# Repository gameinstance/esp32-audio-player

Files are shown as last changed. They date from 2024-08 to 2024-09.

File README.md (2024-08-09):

GameInstance.com esp32 audio player

# esp32-audio-player - GameInstance.com

A PCM56 stereo player powered by ESP32.

Follow the instructions on the [Firmware](./firmware) page to build the code, then flash it onto the
[Hardware](./hardware).

Further details on: https://gameinstance.com/post/106/ESP32-PCM56-player

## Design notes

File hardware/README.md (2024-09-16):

GameInstance.com esp32 audio player

# esp32-audio-player - GameInstance.com

An ESP32 audio player powered by PCM56 DAC chips.

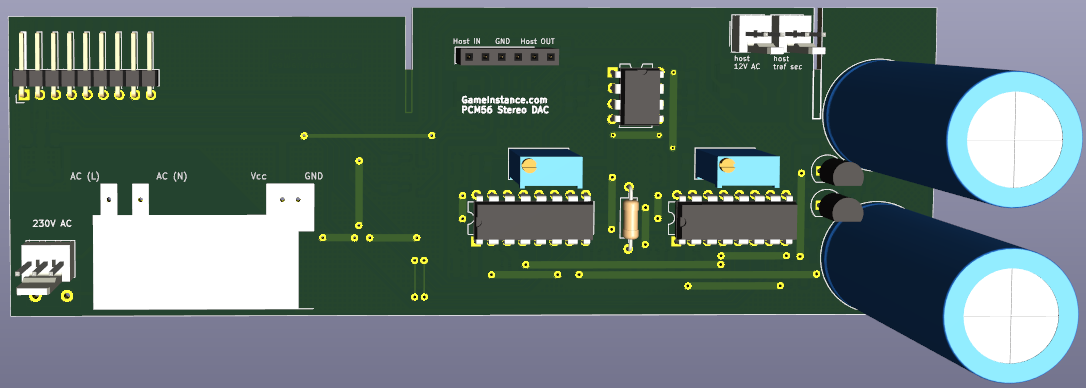
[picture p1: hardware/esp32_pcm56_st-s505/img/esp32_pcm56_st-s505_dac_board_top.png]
ESP32 DAC56 player implementation for Technics ST-S505


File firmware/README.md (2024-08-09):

GameInstance.com esp32 audio player

# esp32-audio-player - GameInstance.com

An ESP32 audio player powered by PCM56 DAC chips.

## Setup

Create the work directory in which you'll clone the **esp32-audio-player** repository and its
dependencies: **basics**, **stream**, **audio**, **esp-idf-cpp**.

```
mkdir ~/gameinstance
cd ~/gameinstance
git clone https://github.com/gameinstance/basics
git clone https://github.com/gameinstance/stream
git clone https://github.com/gameinstance/audio
git clone https://github.com/gameinstance/esp-idf-cpp
git clone https://github.com/gameinstance/esp32-audio-player
```

## Prerequisite

* [ESP-IDF](https://docs.espressif.com/projects/esp-idf/en/stable/esp32/get-started/index.html) environment,
* the [player hardware](../hardware) implementation or a breadboard prototype,
* a serial connection to the ESP32 controller with control over the flashing GPIO pins,
* WIFI_AP and WIFI_PASS configuration in **esp32-audio-player/firmware/main/esp32-audio-player.cc** .

## Build and flash

```
cd ~/gameinstance/esp32-audio-player/firmware
idf.py build flash monitor

```

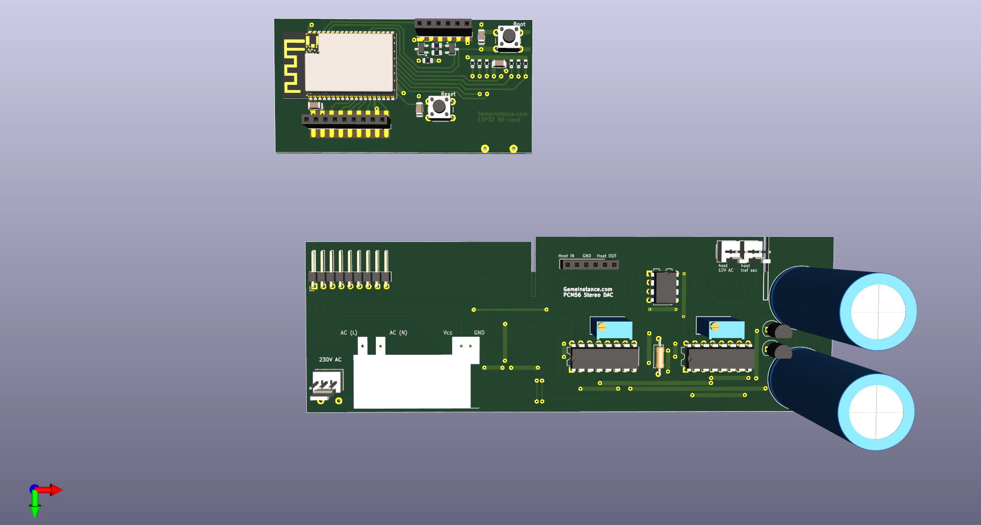
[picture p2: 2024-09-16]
hardware/esp32_pcm56_st-s505/img/esp32_pcm56_simple12.png

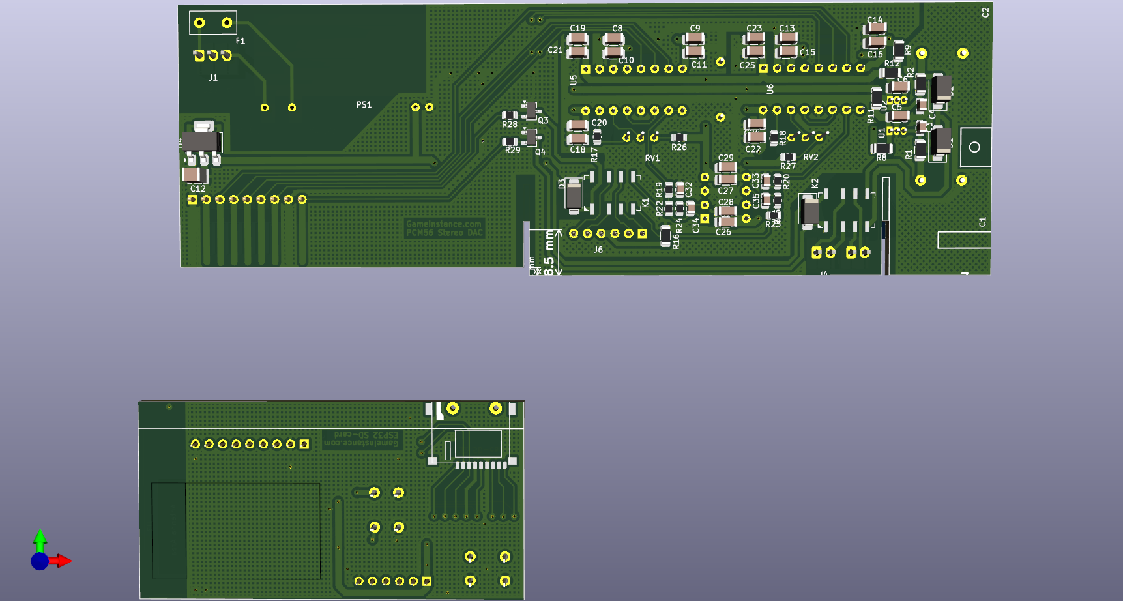
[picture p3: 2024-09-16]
hardware/esp32_pcm56_st-s505/img/esp32_pcm56_simple10.png

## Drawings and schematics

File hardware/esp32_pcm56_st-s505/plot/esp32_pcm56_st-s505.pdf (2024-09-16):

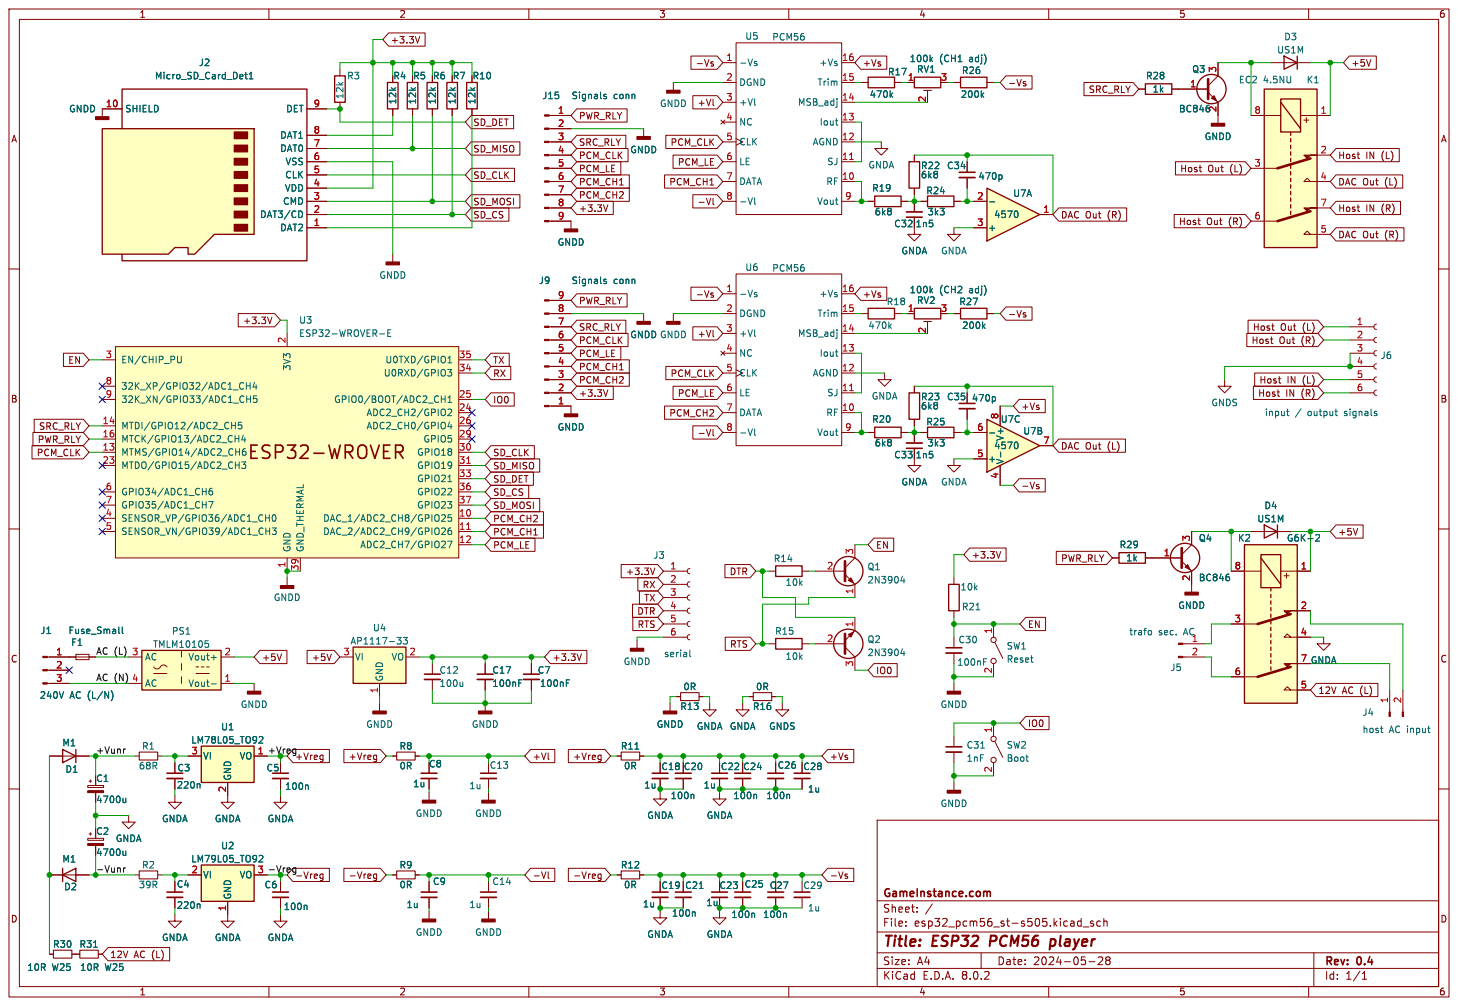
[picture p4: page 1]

Iout 13 MSB_adj 14 Trim 15 +Vs 16 DGND 2 +Vl 3 NC 4 CLK 5
3k3 GNDA R17

6k8 GNDA
input / output signals GND
2N3904 GNDD þÿESP32--WROVER GND

1 VI 2 VO 3 GNDA GNDA GNDA GNDA C6

Id: 1/1 Title: ESP32 PCM56 player File: esp32_pcm56_st-s505.kicad_sch Sheet: / GameInstance.com

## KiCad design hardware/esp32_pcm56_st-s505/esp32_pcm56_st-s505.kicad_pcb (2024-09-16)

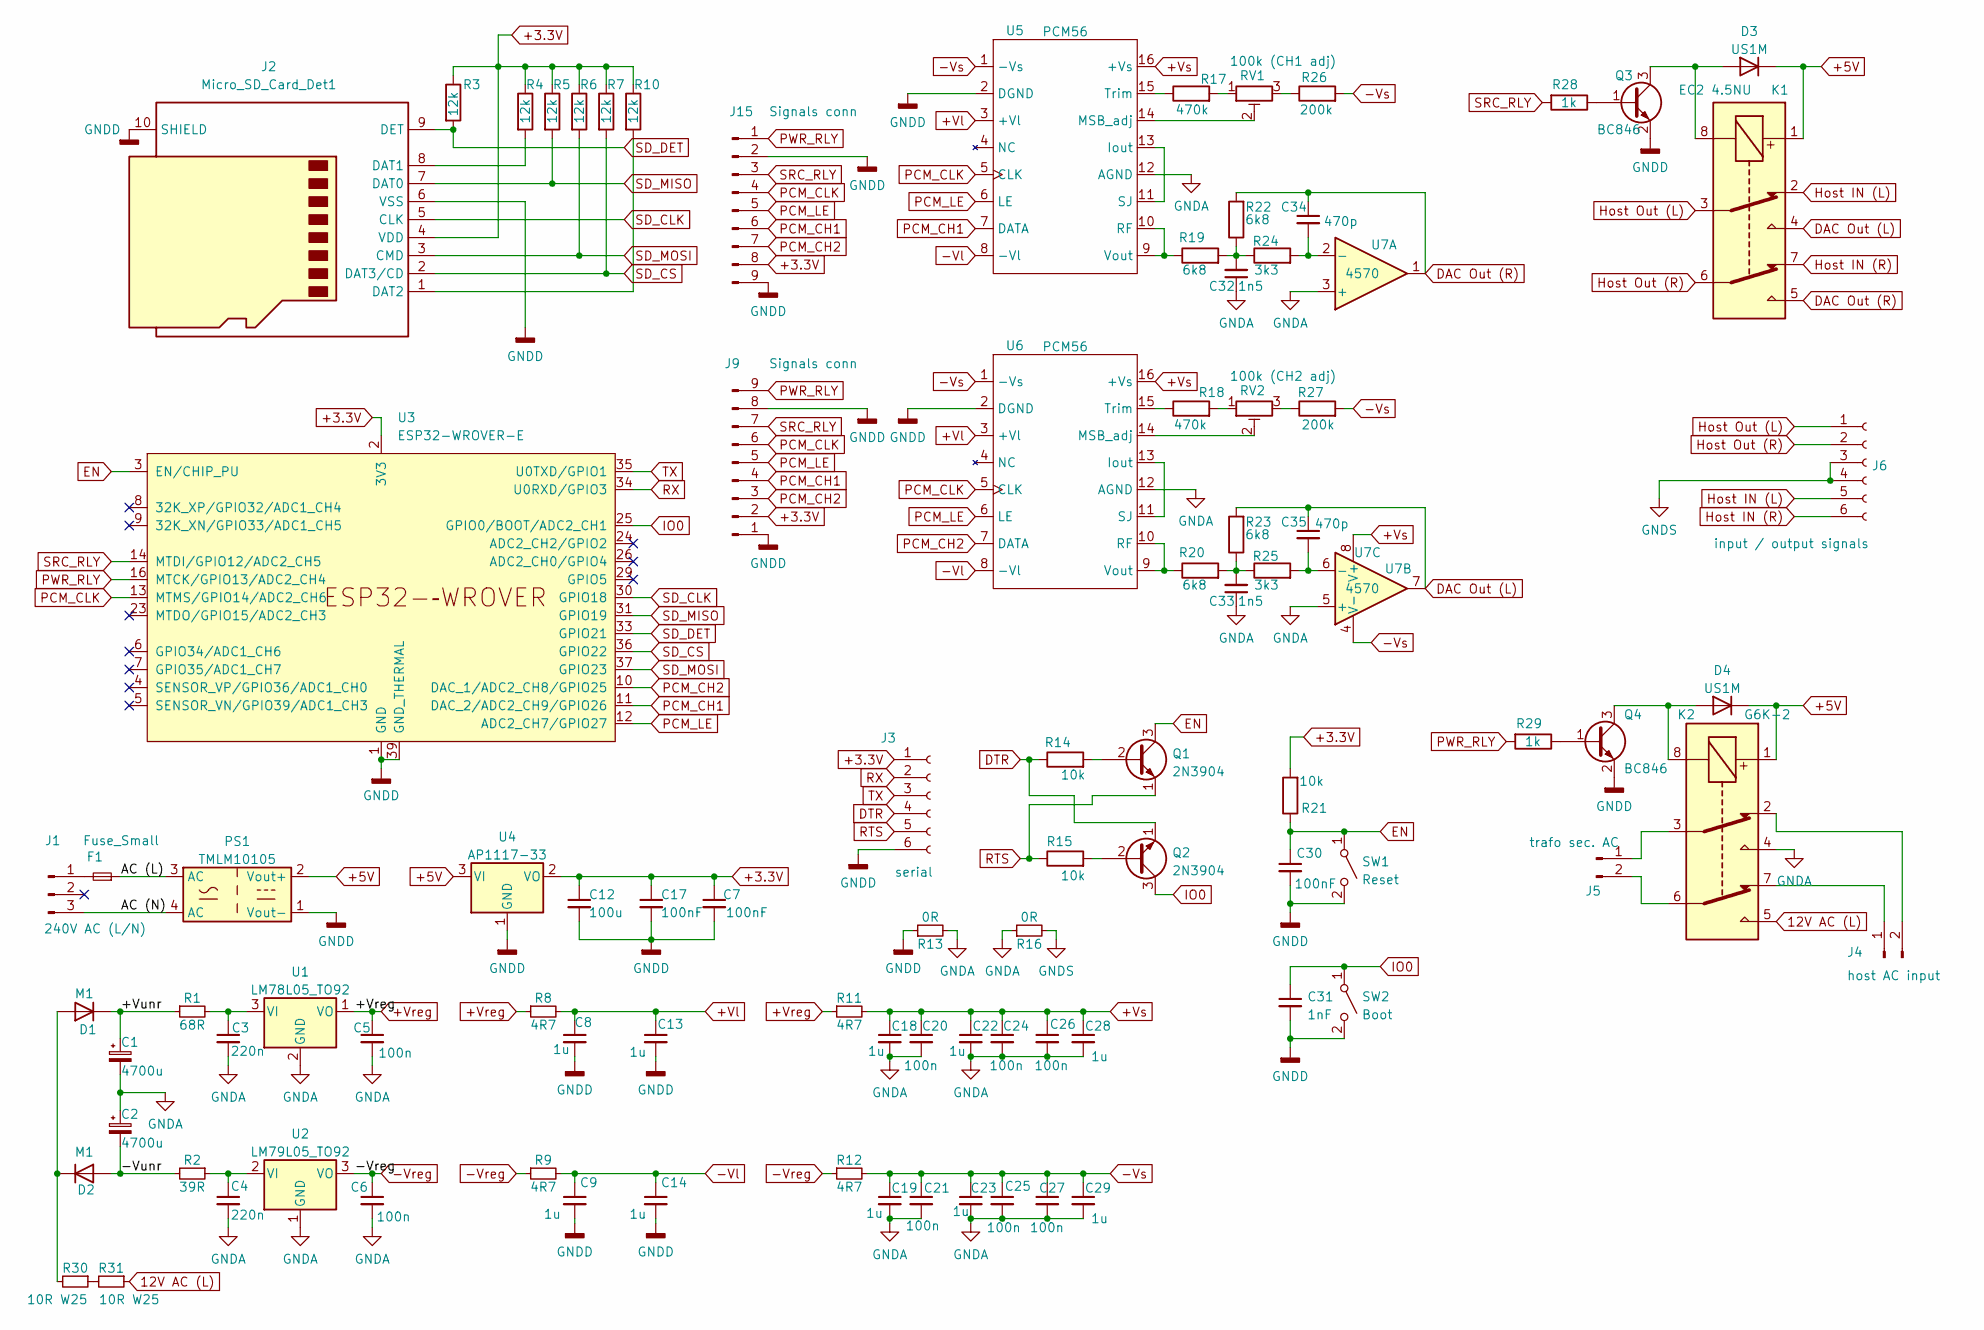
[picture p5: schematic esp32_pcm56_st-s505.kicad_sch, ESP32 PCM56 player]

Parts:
C1, C2: 4700u; C_Radial_D18.0mm_H35.5mm_P7.50mm
C3, C4: 220n; C_0805_2012Metric
C5, C6, C20, C21, C24, C25, C26, C27: 100n; C_1206_3216Metric
C7, C17, C30: 100nF; C_1206_3216Metric
C8, C9, C13, C14, C18, C19, C22, C23, C28, C29: 1u; C_1206_3216Metric
C12: 100u; C_1210_3225Metric
C31: 1nF; C_1206_3216Metric
C32, C33: 1n5; C_0805_2012Metric
C34, C35: 470p; C_0805_2012Metric
D1, D2: M1; D_SMA
D3, D4: US1M; D_SMA
F1: Fuse_Small; Fuse_Littelfuse_395Series
J1: 240V AC (L/N); Molex_KK-254_AE-6410-03A_1x03_P2.54mm_Vertical
J2: Micro_SD_Card_Det1; CTF-11081-P
J3: serial; PinSocket_1x06_P2.54mm_Vertical
J4: host AC input; Molex_KK-254_AE-6410-02A_1x02_P2.54mm_Vertical
J5: trafo sec. AC; Molex_KK-254_AE-6410-02A_1x02_P2.54mm_Vertical
J6: input / output signals; PinSocket_1x06_P2.54mm_Vertical
J9: Signals conn; PinHeader_1x09_P2.54mm_Horizontal
J15: Signals conn; PinSocket_1x09_P2.54mm_Vertical
K1: EC2 4.5NU; Relay_2P2T_10x6mm_TE_IMxxG
K2: G6K-2; Relay_2P2T_10x6mm_TE_IMxxG
PS1: TMLM10105; RPDZN E10W
Q1, Q2: 2N3904; TSOT-23
Q3, Q4: BC846; SOT-23
R1: 68R; R_1206_3216Metric
R2: 39R; R_1206_3216Metric
R3, R4, R5, R6, R7, R10: 12k; R_0603_1608Metric
R8, R9, R11, R12: 4R7; R_1206_3216Metric
R13: 0R; R_Axial_DIN0207_L6.3mm_D2.5mm_P10.16mm_Horizontal
R14, R15, R21: 10k; R_0805_2012Metric
R16: 0R; R_1206_3216Metric
R17, R18: 470k; R_0805_2012Metric
R19, R20, R22, R23: 6k8; R_0805_2012Metric
R24, R25: 3k3; R_0805_2012Metric
R26, R27: 200k; R_0805_2012Metric
R28, R29: 1k; R_0805_2012Metric
R30, R31: 10R W25; R_1206_3216Metric
RV1: 100k (CH1 adj); Potentiometer_Bourns_3296W_Vertical
RV2: 100k (CH2 adj); Potentiometer_Bourns_3296W_Vertical
SW1: Reset; SW_PUSH_6mm_H5mm
SW2: Boot; SW_PUSH_6mm_H5mm
U1: LM78L05_TO92; TO-92_Inline
U2: LM79L05_TO92; TO-92_Inline
U3: ESP32-WROVER-E
U4: AP1117-33; SOT-223-3_TabPin2
U5, U6: PCM56; DIP-16_W7.62mm
U7: 4570; DIP-8_W7.62mm

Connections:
12V AC (L): K2.5, R31.1
+3.3V: C7.1, C12.1, C17.1, J2.4 (VDD), J3.1, J9.2, J15.8, R3.1, R4.1, R5.1, R6.1, R7.1, R10.1, R21.2, U3.2 (3V3), U4.2 (VO)
+5V: D3.1 (K), D4.1 (K), K1.1, K2.1, PS1.2 (Vout+), U4.3 (VI)
+Vl: C8.1, C13.1, R8.2, U5.3 (+Vl), U6.3 (+Vl)
+Vreg: C5.1, R8.1, R11.1, U1.1 (VO)
+Vs: C18.1, C20.1, C22.1, C24.1, C26.1, C28.1, R11.2, U5.16 (+Vs), U6.16 (+Vs), U7.8 (V+)
-Vl: C9.1, C14.1, R9.2, U5.8 (-Vl), U6.8 (-Vl)
-Vreg: C6.1, R9.1, R12.1, U2.3 (VO)
-Vs: C19.1, C21.1, C23.1, C25.1, C27.1, C29.1, R12.2, R26.2, R27.2, U5.1 (-Vs), U6.1 (-Vs), U7.4 (V-)
/+Vunr: C1.1, D1.1 (K), R1.1
/-Vunr: C2.2, D2.2 (A), R2.2
/AC (L): F1.1, PS1.3 (AC)
/AC (N): J1.3, PS1.4 (AC)
DAC Out (L): C35.1, K1.4, R23.2, U7.7
DAC Out (R): C34.1, K1.5, R22.2, U7.1
DTR: J3.4, Q2.1 (E), R14.1
EN: C30.1, Q1.3 (C), R21.1, SW1.1 (A), U3.3 (EN/CHIP_PU)
GNDA: C1.2, C2.1, C3.2, C4.2, C5.2, C6.2, C18.2, C19.2, C20.2, C21.2, C22.2, C23.2, C24.2, C25.2, C26.2, C27.2, C28.2, C29.2, C32.1, C33.1, K2.4, R13.2, R16.1, U1.2 (GND), U2.1 (GND), U5.12 (AGND), U6.12 (AGND), U7.3 (+), U7.5 (+)
GNDD: C7.2, C8.2, C9.2, C12.2, C13.2, C14.2, C17.2, C30.2, C31.2, J2.6 (VSS), J2.10 (SHIELD), J3.6, J9.1, J9.8, J15.2, J15.9, PS1.1 (Vout-), Q3.2 (E), Q4.2 (E), R13.1, SW1.2 (B), SW2.2 (B), U3.1 (GND), U3.15 (GND), U3.38 (GND), U3.39 (GND_THERMAL), U4.1 (GND), U5.2 (DGND), U6.2 (DGND)
GNDS: J6.3, J6.4, R16.2
Host IN (L): J6.5, K1.2
Host IN (R): J6.6, K1.7
Host Out (L): J6.1, K1.3
Host Out (R): J6.2, K1.6
IO0: C31.1, Q2.3 (C), SW2.1 (A), U3.25 (GPIO0/BOOT/ADC2_CH1)
unnamed: C32.2, R19.2, R22.1, R24.1
unnamed: C33.2, R20.2, R23.1, R25.1
unnamed: D1.2 (A), D2.1 (K), R30.2
unnamed: D3.2 (A), K1.8, Q3.3 (C)
unnamed: D4.2 (A), K2.8, Q4.3 (C)
unnamed: F1.2, J1.1
unnamed: J2.8 (DAT1), R4.2
unnamed: J2.1 (DAT2), R10.2
unnamed: J4.1, K2.7
unnamed: J4.2, K2.2
unnamed: J5.1, K2.3
unnamed: J5.2, K2.6
unnamed: Q1.2 (B), R14.2
unnamed: Q2.2 (B), R15.2
unnamed: Q3.1 (B), R28.1
unnamed: Q4.1 (B), R29.1
unnamed: R17.2, RV1.1
unnamed: R18.2, RV2.1
unnamed: R26.1, RV1.3
unnamed: R27.1, RV2.3
unnamed: R30.1, R31.2
unnamed: C3.1, R1.2, U1.3 (VI)
unnamed: C4.1, R2.1, U2.2 (VI)
unnamed: U5.11 (SJ), U5.13 (Iout)
unnamed: RV1.2, U5.14 (MSB_adj)
unnamed: R19.1, U5.9 (Vout), U5.10 (RF)
unnamed: R17.1, U5.15 (Trim)
unnamed: U6.11 (SJ), U6.13 (Iout)
unnamed: RV2.2, U6.14 (MSB_adj)
unnamed: R20.1, U6.9 (Vout), U6.10 (RF)
unnamed: R18.1, U6.15 (Trim)
unnamed: C34.2, R24.2, U7.2 (-)
unnamed: C35.2, R25.2, U7.6 (-)
PCM_CH1: J9.4, J15.6, U3.11 (DAC_2/ADC2_CH9/GPIO26), U5.7 (DATA)
PCM_CH2: J9.3, J15.7, U3.10 (DAC_1/ADC2_CH8/GPIO25), U6.7 (DATA)
PCM_CLK: J9.6, J15.4, U3.13 (MTMS/GPIO14/ADC2_CH6), U5.5 (CLK), U6.5 (CLK)
PCM_LE: J9.5, J15.5, U3.12 (ADC2_CH7/GPIO27), U5.6 (LE), U6.6 (LE)
PWR_RLY: J9.9, J15.1, R29.2, U3.16 (MTCK/GPIO13/ADC2_CH4)
RTS: J3.5, Q1.1 (E), R15.1
RX: J3.2, U3.34 (U0RXD/GPIO3)
SD_CLK: J2.5 (CLK), U3.30 (GPIO18)
SD_CS: J2.2 (DAT3/CD), R7.2, U3.36 (GPIO22)
SD_DET: J2.9 (DET), R3.2, U3.33 (GPIO21)
SD_MISO: J2.7 (DAT0), R5.2, U3.31 (GPIO19)
SD_MOSI: J2.3 (CMD), R6.2, U3.37 (GPIO23)
SRC_RLY: J9.7, J15.3, R28.2, U3.14 (MTDI/GPIO12/ADC2_CH5)
TX: J3.3, U3.35 (U0TXD/GPIO1)

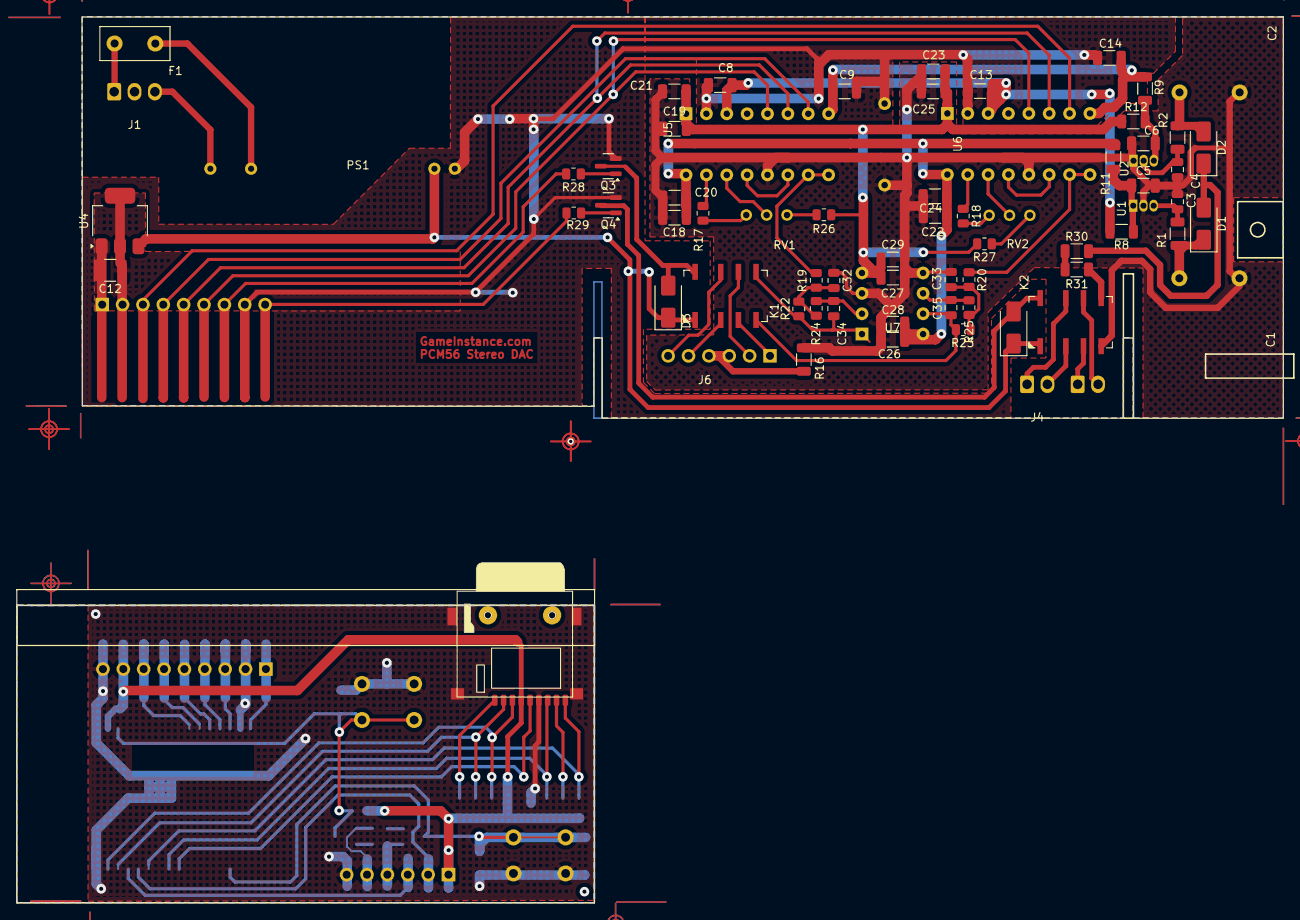
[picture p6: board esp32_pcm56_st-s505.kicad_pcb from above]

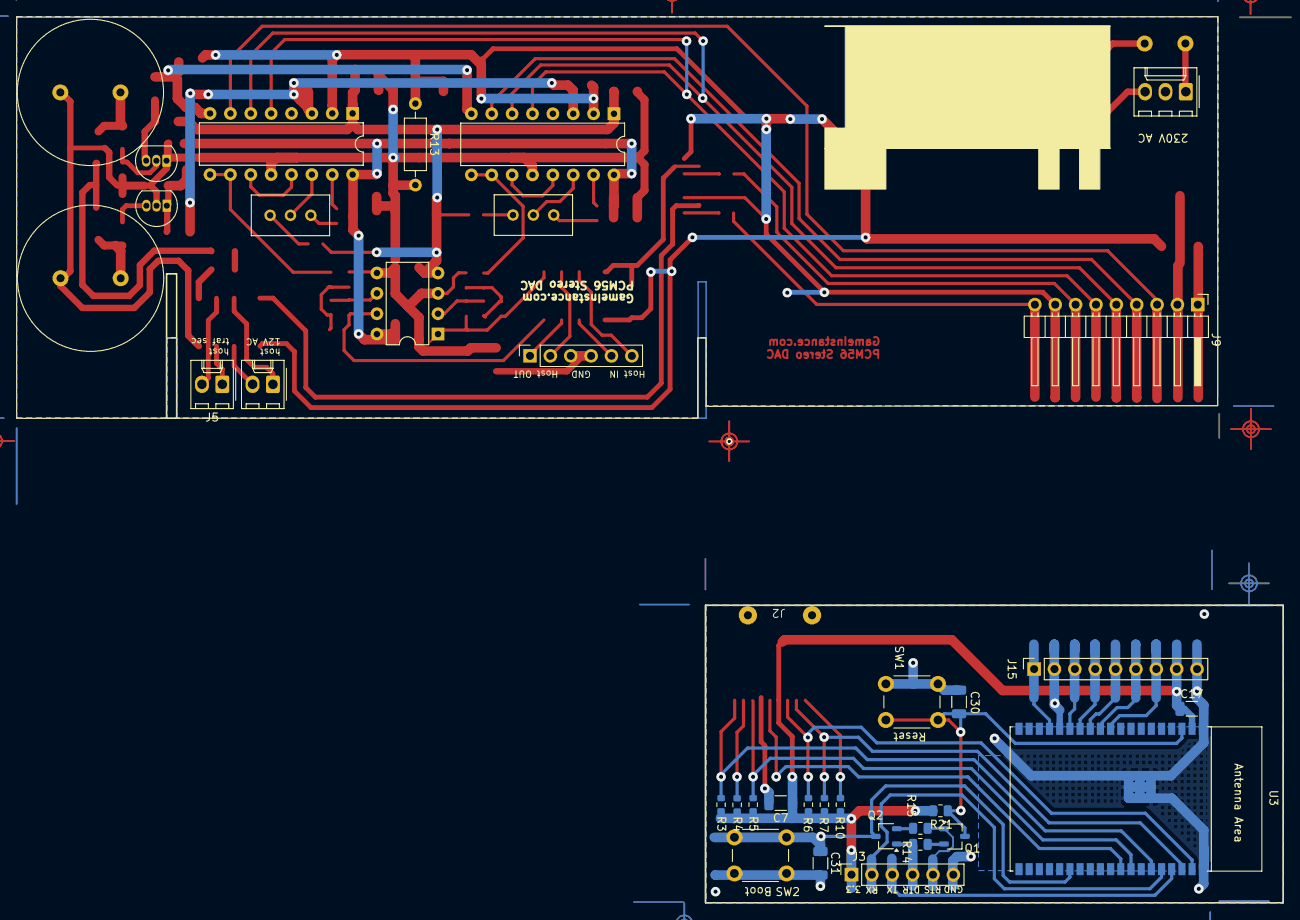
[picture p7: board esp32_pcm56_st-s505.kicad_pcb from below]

Board: 2 copper layers, 157.9 x 110.5 mm, 93 parts (36 on the bottom side), 72 nets.

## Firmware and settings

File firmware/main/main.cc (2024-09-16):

/* Copyright (C) 2024  Bogdan-Gabriel Alecu  (GameInstance.com)
 *
 * esp32-audio-player - yet another esp32 audio player
 *
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
 * You should have received a copy of the GNU General Public License along with this program.
 * If not, see <https://www.gnu.org/licenses/>.
 */

#include <stdio.h>
#include <dirent.h>
#include <iostream>
#include <sstream>
#include <cstring>
#include <algorithm>
#include "esp_http_server.h"
#include "sdmmc_cmd.h"

#include <basics/file.hh>
#include <basics/base64.hh>
#include <audio/flac.hh>
#include <defs.hh>
#include <gpio.hh>
#include <nvs_partition.hh>
#include <wifi.hh>
#include <spi_bus.hh>
#include <spi_sd.hh>
#include <stream_buffer.hh>
#include <player.hh>


//      SPI       GPIO    SD     SDSPI  MMC
// ----------------------------------------
#define SD_CS     22   // DAT3   CS     RES
#define SD_SCK    18   // CLK    SCLK   CLK
#define SD_MOSI   23   // CMD    DI     CMD
#define SD_MISO   19   // DAT0   DO     DAT
#define SD_DET    21   // xxx    xxx    xxx

#define PCM_CLK       14
#define PCM_LE        27
#define PCM_CH1_DATA  26
#define PCM_CH2_DATA  25

#define SRC_RLY  12
#define PWR_RLY  13

static const unsigned char wifi_ssid[32] = "WIFI_AP";
static const unsigned char wifi_pasw[64] = "WIFI_PASS";

static const double frequency_calibration = 0.995428; //ideally: 1, adjusted by trial-and-error;
static const uint16_t buffer_max_size = 4608;
static const uint8_t buffer_max_count = 2;

using player_buffer_type = stream_buffer<stereo_sample_type, buffer_max_size>;
using pcm56_player_type = stereo_player<player_buffer_type>;
using input_file_type = basics::file::input<1024>;
using flac_decoder_type = audio::flac::decoder<input_file_type, buffer_max_size>;

enum class cmd_type: uint8_t {
	idle,
	list,
	play,
	stop,
};
enum class state_type: uint8_t {
	init,
	has_connection,
	has_storage,
	ready = has_storage,
	play,
};
enum class play_mode_type: uint8_t {
	once,
	loop,
	album
};


auto bus_config = esp::io::spi_bus_config{
	.sck_pin  = SD_SCK,  // SD#CLK,
	.mosi_pin = SD_MOSI, // SD#CMD,
	.miso_pin = SD_MISO, // SD#DAT0,
	.quadwp_pin = -1,    // SD#DAT2,
	.quadhd_pin = -1,    // SD#DAT3,
	.max_transfer_size = buffer_max_size,
	.core_affinity = esp::io::cpu_core_affinity::cpu_core_0,
};
auto sd_config = esp::io::spi_sd_config{
	.spi_bus = bus_config,
	.cs_pin = SD_CS,
};
auto player_config = stereo_player_config {
	.clk_gpio      = PCM_CLK,
	.ch1_data_gpio = PCM_CH1_DATA,
	.ch2_data_gpio = PCM_CH2_DATA,
	.le_gpio       = PCM_LE,
};
auto relays_config = pcm56_player::relays_output_config {
	.source_gpio = SRC_RLY,
	.power_gpio = PWR_RLY,
};
auto card_detect_config = pcm56_player::card_detect_input_config {
	.gpio = SD_DET,
};

auto player_buffer = player_buffer_type{};
auto cmd = cmd_type{};
auto state = state_type{};
auto current_dir = std::string{"/"};
auto play_mode = play_mode_type{};
auto play_dir = std::string{"/"};
auto play_file = std::string{};
auto play_path = std::string{};
auto volume = int16_t{0};

pcm56_player::relays_output relays{relays_config};
pcm56_player::card_detect_input card_detect{card_detect_config};


std::string get_next_album_track()
{
	std::string dir_path{sd_config.mount_point};
	dir_path += play_dir;

	DIR *dp = ::opendir(dir_path.c_str());
	if (dp == nullptr)
		throw basics::error{"failed opening dir '%s'", dir_path.c_str()};

	std::vector<std::string> files{};
	struct dirent *ep = nullptr;
	for (;;) {
		ep = ::readdir(dp);
		if (ep == nullptr)
			break;

		if (ep->d_type == DT_DIR)
			continue;

		// TODO: filter unsupported files
		files.emplace_back(ep->d_name);
	}
	::closedir(dp);

	taskYIELD();

	std::sort(files.begin(), files.end());
	size_t i = 0;
	for (; i < files.size() - 1; ++i) {
		if (files[i] == play_file)
			break;
	}

	play_file = files[i + 1];

	auto res = play_dir;
	res += "/";
	res += play_file;

	return res;
}


void prepare_next_track()
{
	if (play_mode == play_mode_type::once) {
		state = state_type::ready;
	} else if (play_mode == play_mode_type::loop) {
		// play_path remains unchanged
	} else /*if (play_mode == play_mode_type::album)*/ {
		try {
			play_path = get_next_album_track();

			vTaskDelay(1000 / portTICK_PERIOD_MS);
		} catch (basics::error& e) {
			state = state_type::ready;

			e.append("player: mode=album");
			e.dump();
		} catch (const std::exception &e) {
			state = state_type::ready;

			std::cerr << "error: mode=album: " << e.what() << std::endl;
			;
		}
	}
}


void play_track()
{
	std::string file_path{sd_config.mount_point};
	file_path += play_path;
	input_file_type file_istream{file_path.data()};
	flac_decoder_type flac_decoder{file_istream};
	std::cout << "player: track=" << file_path << std::endl;

	flac_decoder.decode_marker();
	while (flac_decoder.state() != audio::flac::decoder_state::has_metadata)
		flac_decoder.decode_metadata();
	auto info = flac_decoder.streaminfo();
	pcm56_player::print_streaminfo(info);

	int sample_rshift = info.sample_bit_size - player_sample_bit_size;
	std::cout << "player: sample rshifting by " << sample_rshift << " bits\n";

	player_buffer.reset();

	{
		pcm56_player_type player{player_config, player_buffer, info.sample_rate, frequency_calibration};

		auto have_block = false;
		for (;;) {
			if (cmd == cmd_type::stop) {
				cmd = cmd_type::idle;
				state = state_type::ready;
				std::cout << "player: cmd=stop" << std::endl;

				break;
			}

			if (cmd == cmd_type::play) {
				cmd = cmd_type::idle;
				state = state_type::play;
				std::cout << "player: cmd=play" << std::endl;

				break;
			}

			if (!have_block) {
				flac_decoder.decode_audio();
				have_block = true;

				continue;
			}

			// have_block
			if (!player_buffer.need_data()) {
				taskYIELD();

				continue;
			}

			int rshift = sample_rshift - volume;

			if (rshift == 0) {
				for (auto i = size_t{0}; i < flac_decoder.block_size(); ++i)
					player_buffer.template put<task_operation>(stereo_sample_type{
						(player_sample_type)flac_decoder.block_data()[0][i],
										(player_sample_type)flac_decoder.block_data()[1][i]});
			} else if (rshift >= 0) {
				for (auto i = size_t{0}; i < flac_decoder.block_size(); ++i)
					player_buffer.template put<task_operation>(stereo_sample_type{
						(player_sample_type)(flac_decoder.block_data()[0][i] >> rshift),
										(player_sample_type)(flac_decoder.block_data()[1][i] >> rshift)});
			} else { // (rshift < 0)
				for (auto i = size_t{0}; i < flac_decoder.block_size(); ++i)
					player_buffer.template put<task_operation>(stereo_sample_type{
						(player_sample_type)(flac_decoder.block_data()[0][i] << -rshift),
										(player_sample_type)(flac_decoder.block_data()[1][i] << -rshift)});
			}
			have_block = false;

			if (flac_decoder.state() == audio::flac::decoder_state::complete)
				break;

			taskYIELD();
		}
	}

	if ((state == state_type::play) && (flac_decoder.state() == audio::flac::decoder_state::complete))
		prepare_next_track();
}


httpd_uri_t main_page_handler = {
	.uri = "/",
	.method = HTTP_GET,
	.handler = [] (httpd_req_t *req) -> esp_err_t {
		return httpd_resp_send(req, pcm56_player::web_page, HTTPD_RESP_USE_STRLEN);
	},
	.user_ctx = nullptr
};

httpd_uri_t list_handler = {
	.uri = "/list",
	.method = HTTP_GET,
	.handler = [] (httpd_req_t *req) -> esp_err_t {
		try {
			std::string dir_path = std::string{req->uri}.substr(6);  // HACK: parse params properly
			dir_path = basics::base64::decode(dir_path.c_str(), dir_path.size());
			std::cout << "http_ui: GET /list " << req->uri << "; dir=" << dir_path << std::endl;

			if (!card_detect.card_present())
				throw basics::error{"sd_card: no card present"};

			current_dir = dir_path;
			dir_path = sd_config.mount_point + dir_path;

			DIR *dp = nullptr;
			dp = ::opendir(dir_path.c_str());
			if (dp == nullptr)
				throw basics::error{"httpd: failed opening dir '%s'", dir_path.c_str()};

			bool first{true};
			struct dirent *ep = nullptr;

			std::stringstream ostream{};

			httpd_resp_set_type(req, "application/json");
			ostream << "[";
			for (;;) {
				ep = ::readdir(dp);
				if (ep == nullptr)
					break;

				ostream << (first? "" : ",")
						<< "{\"t\":\"" << ((ep->d_type == DT_DIR)? "d" : "f") << "\",\"n\":\""
						<< ep->d_name << "\"}";
				first = false;
			}
			::closedir(dp);

			ostream << "]";
			return httpd_resp_sendstr(req, ostream.str().c_str());

		} catch (...) {
			return httpd_resp_sendstr(req, "error");
		}
	},
	.user_ctx = nullptr
};

httpd_uri_t play_handler = {
	.uri = "/play",
	.method = HTTP_GET,
	.handler = [] (httpd_req_t *req) -> esp_err_t {
		try {
			play_path = std::string{req->uri}.substr(6);  // TODO: create a param parser
			play_path = basics::base64::decode(play_path.c_str(), play_path.size());
			std::cout << "http_ui: GET " << req->uri << "; file=" << play_path << std::endl;

			if (!card_detect.card_present())
				return httpd_resp_send(req, "[error: no card]", HTTPD_RESP_USE_STRLEN);

			{
				std::string file_path{sd_config.mount_point};
				file_path += play_path;
				basics::file::input<512> file_istream{file_path.data()};
				auto streaminfo = audio::flac::decode_metadata(file_istream);

				if (streaminfo.channel_count > player_channel_count)
					return httpd_resp_send(req, "[error: not stereo]", HTTPD_RESP_USE_STRLEN);
				if (streaminfo.sample_rate > player_sample_rate)
					return httpd_resp_send(req, "[error: bad rate]", HTTPD_RESP_USE_STRLEN);
			}

			auto pos = play_path.rfind('/');
			play_file = (pos == std::string::npos)? play_path : play_path.substr(pos + 1);
			play_dir = play_path.substr(0, pos);

			cmd = cmd_type::play;

			return httpd_resp_send(req, "play", HTTPD_RESP_USE_STRLEN);
		} catch (basics::error& e) {
			e.append("bad header");
			e.dump();

			return httpd_resp_send(req, "[error: bad header]", HTTPD_RESP_USE_STRLEN);
		} catch (/*basics::error &e*/...) {
			std::cout << "error: cannot play" << std::endl;

			return httpd_resp_send(req, "[error: cannot play]", HTTPD_RESP_USE_STRLEN);
		}
	},
	.user_ctx = nullptr
};

httpd_uri_t stop_handler = {
	.uri = "/stop",
	.method = HTTP_GET,
	.handler = [] (httpd_req_t *req) -> esp_err_t {
		cmd = cmd_type::stop;

		std::cout << "http_ui: GET " << req->uri << std::endl;
		return httpd_resp_send(req, "stop", HTTPD_RESP_USE_STRLEN);
	},
	.user_ctx = nullptr
};

httpd_uri_t volume_handler = {
	.uri = "/volume",
	.method = HTTP_GET,
	.handler = [] (httpd_req_t *req) -> esp_err_t {
		httpd_resp_set_type(req, "application/json");

		if (std::string{req->uri}.substr(8) == "up") {
			if (volume < 1)
				++volume;
		} else {
			if (volume > -6)
				--volume;
		}

		std::stringstream ostream{};
		ostream << "{\"volume\":" << volume << "}";

		std::cout << "http_ui: GET " << req->uri << " " << ostream.str() << std::endl;
		return httpd_resp_sendstr(req, ostream.str().c_str());
	},
	.user_ctx = nullptr
};

httpd_uri_t mode_handler = {
	.uri = "/mode",
	.method = HTTP_GET,
	.handler = [] (httpd_req_t *req) -> esp_err_t {
		httpd_resp_set_type(req, "application/json");

		auto mode = std::string{req->uri}.substr(6);

		if (mode == "once") {
			play_mode = play_mode_type::once;
		} else if (mode == "loop") {
			play_mode = play_mode_type::loop;
		} else /*if (mode == "album")*/ {
			play_mode = play_mode_type::album;
		}

		std::stringstream ostream{};
		ostream << "{\"mode\":\"" << mode << "\"}";

		std::cout << "http_ui: GET " << req->uri << " " << ostream.str() << std::endl;
		return httpd_resp_sendstr(req, ostream.str().c_str());
	},
	.user_ctx = nullptr
};

httpd_uri_t state_handler = {
	.uri = "/state",
	.method = HTTP_GET,
	.handler = [] (httpd_req_t *req) -> esp_err_t {
		httpd_resp_set_type(req, "application/json");

		std::stringstream ostream{};
		ostream << "{\"status\":\"" << ((state == state_type::init)? "starting..." :
										(state == state_type::has_connection)? "no sd-card" :
										(state == state_type::ready)? "ready" : "playing") << "\","
				<< "\"dir\":\""  << ((state == state_type::play)? play_dir : current_dir) << "\","
				<< "\"file\":\"" << ((state == state_type::play)? play_file : "") << "\","
				<< "\"mode\":\"" << ((play_mode == play_mode_type::once)? "once" :
									 (play_mode == play_mode_type::loop)? "loop" : "album") << "\","
				<< "\"volume\":" << volume << "}";

		std::cout << "http_ui: GET " << req->uri << " : " << ostream.str() << std::endl;
		return httpd_resp_sendstr(req, ostream.str().c_str());
	},
	.user_ctx = nullptr
};

httpd_handle_t setup_server(void)
{
	httpd_config_t config = HTTPD_DEFAULT_CONFIG();
	httpd_handle_t server = nullptr;

	if (httpd_start(&server, &config) == ESP_OK) {
		httpd_register_uri_handler(server, &main_page_handler);
		httpd_register_uri_handler(server, &list_handler);
		httpd_register_uri_handler(server, &play_handler);
		httpd_register_uri_handler(server, &stop_handler);
		httpd_register_uri_handler(server, &volume_handler);
		httpd_register_uri_handler(server, &mode_handler);
		httpd_register_uri_handler(server, &state_handler);
	}

	return server;
}


void player_main()
{
	state = state_type::ready;

	for (;;) {
		if (!card_detect.card_present()) {
			std::cout << "player: SD card removed!" << std::endl;

			break;
		}

		if (state == state_type::ready) {
			if (cmd == cmd_type::play) {
				cmd = cmd_type::idle;

				state = state_type::play;
			}
		}

		if (state == state_type::play) {
			relays.set(true);

			try {
				play_track();
			} catch (basics::error& e) {
				e.append("player failure");
				e.dump();

				state = state_type::ready;

				vTaskDelay(1000 / portTICK_PERIOD_MS);
			} catch (const std::exception &e) {
				std::cerr << "player failure: " << e.what() << std::endl;
				throw;
			}
		}

		if (state != state_type::play)
			relays.set(false);

		vTaskDelay(25 / portTICK_PERIOD_MS);
	}
}


void user_main()
{
	for (;;) {
		try {
			state = state_type::has_connection;

			if (!card_detect.card_present())
				throw basics::error{"no SD card present"};

			esp::io::spi_bus bus{bus_config};
			sdmmc_host_t host = SDSPI_HOST_DEFAULT();
			esp::io::spi_sd_deps sd_deps{host};
			esp::io::spi_sd sd{sd_config, sd_deps};

			state = state_type::has_storage;

			sdmmc_card_print_info(stdout, sd.card());
			std::cout << "user: system ready" << std::endl;

			taskYIELD();

			player_main();
		} catch (basics::error& e) {
			e.append("user failure");
			e.dump();
		} catch (std::exception &e) {
			std::cerr << "user failure: " << e.what() << std::endl;
		}

		vTaskDelay(1000 / portTICK_PERIOD_MS);
	}
}


// wifi task   -> core 1 : menuconfig → Component config → Wi-Fi
// tcp/ip task -> core 1 : menuconfig → Component config → LWIP
// main task   -> core 0 : menuconfig → Component config → ESP System Settings → Main task core affinity
// interrupt watchdog on : menuconfig → Component config → ESP System Settings → [-] Interrupt watchdog
// task watchdog timer on: menuconfig → Component config → ESP System Settings → [-] Enable Task Watchdog Timer
// esp timer   -> core 0 : menuconfig → Component Config → High resolution timer (esp_timer) → esp_timer task core affinity (CPU0)
// isr timer   -> core 0 : menuconfig → Component Config → High resolution timer (esp_timer) → timer interrupt core affinity (CPU0)
// main stack -> 4600    : menuconfig → Component Config → ESP System settings → Main task stack size (changed from 3584 to 4600)
// CPU freq. -> 240MHz   : menuconfig → Component Config → ESP System settings → CPU frequency (changed from 160MHz to 240MHz)
extern "C" void app_main(void)
{
	for (;;) {
		try {
			state = state_type::init;
			play_mode = play_mode_type::album;

			esp::storage::nvs_partition nvs{};
			esp::io::wifi_sta wifi{wifi_ssid, wifi_pasw};
			setup_server();

			std::cout << "app: networking ready" << std::endl;

			taskYIELD();

			user_main();
		} catch (basics::error& e) {
			e.append("app failure");
			e.dump();
		} catch (std::exception &e) {
			std::cerr << "app failure: " << e.what() << std::endl;
		}

		vTaskDelay(1000 / portTICK_PERIOD_MS);
	}
}

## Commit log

2024-09-16 firmware: corrected player behavior ...
    * removed redundant state updates in prepare_next_track();
    * reduced the scope of the player to minimize fs I/O overlap effects;
    * improved logging for http UI requests;
    * corrected and reduced verbosity for player timer log entries.
    [main.cc]
2024-09-16 hardware: added KiCAD project files for the technics st-s505 implementation
    [esp32_pcm56_st-s505.kicad_pcb, esp32_pcm56_st-s505.kicad_sch]
2024-09-16 Update README.md
    added rendered preview of DAC board implementation for Technics ST-S505

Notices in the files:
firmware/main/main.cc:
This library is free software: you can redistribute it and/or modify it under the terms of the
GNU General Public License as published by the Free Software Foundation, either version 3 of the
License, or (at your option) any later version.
